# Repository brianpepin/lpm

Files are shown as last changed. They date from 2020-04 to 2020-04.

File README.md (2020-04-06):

# LPM
LPM is a laser power meter used for reading the output power of a laser. It is designed to use a power sensor from Ophir, but any sensor that can produce a linear voltage related to power can be used.  It supplies +12 and -12 volt supplies to the sensor to power it, if needed.

## Features
* 24 bit ADC for precision
* Logging to onboard 64KB flash memory
* Logs viewable graphically and can be output to PC using built-on USB serial port
* Rechargeable battery through USB-C connector
* Software calibration can use any sensor

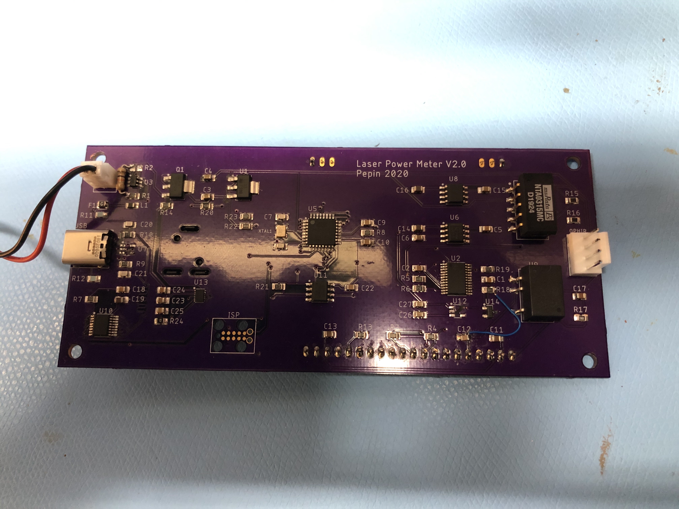
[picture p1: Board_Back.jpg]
Board Back

_(note - the Eagle files included in this repo do not need the jumper and resistor hacks you see here.  They've been fixed)_

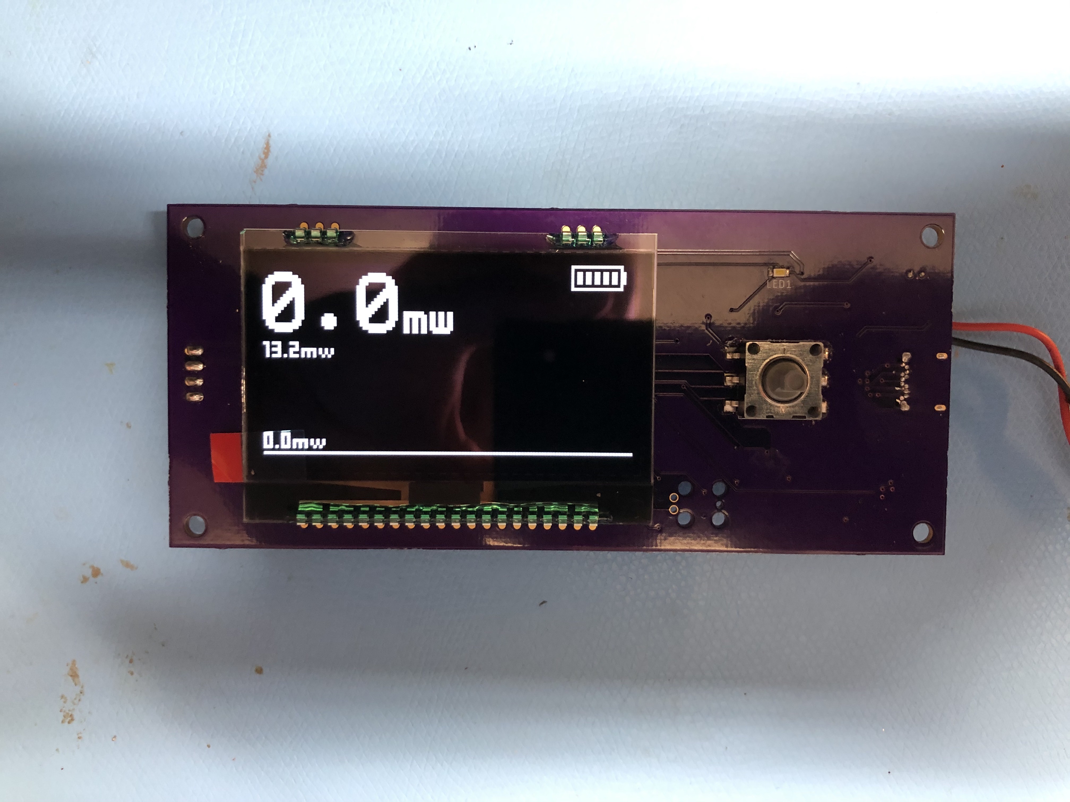
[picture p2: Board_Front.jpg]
Board Front


### Calibration
The board must be calibrated before use.  This can be done through the menu.  Connect a stable voltage source to the sensor input (11.5 volts maximum) and enter the calibration menu.  This will display six digits (###.###), and represents the laser power level at that voltage for the sensor you plan to use.  Use the D-Pad to adjust the digits and click down to accept.

### Usage
Clicking down on the D-Pad turns the unit on. There is an automatic sleep of 10 minutes of inactivity.  Sleep is disabled during logging. Pressing right, left, select or on the D-Pad enters the menu. From here you can zero the max and averages, configure logging cadence or view the log if it exists.  There are also two short-cuts:  down zeros the max and averages and up starts / stops logging. Pressing and holding in the D-Pad for two seconds turns the unit off.

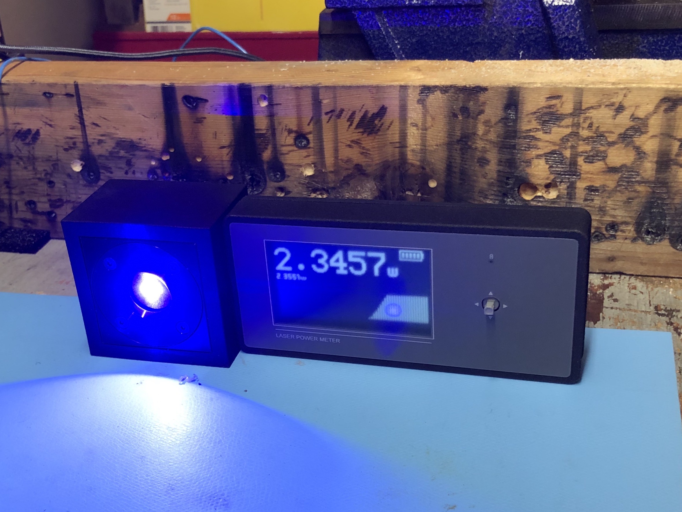
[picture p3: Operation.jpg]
Operation


### Logging
When in logging view you can position the cursor using left and right to show the value at that location.  The log can be sent through USB -- the LPM shows up as a serial port, so you need your own software to pull the log data off.

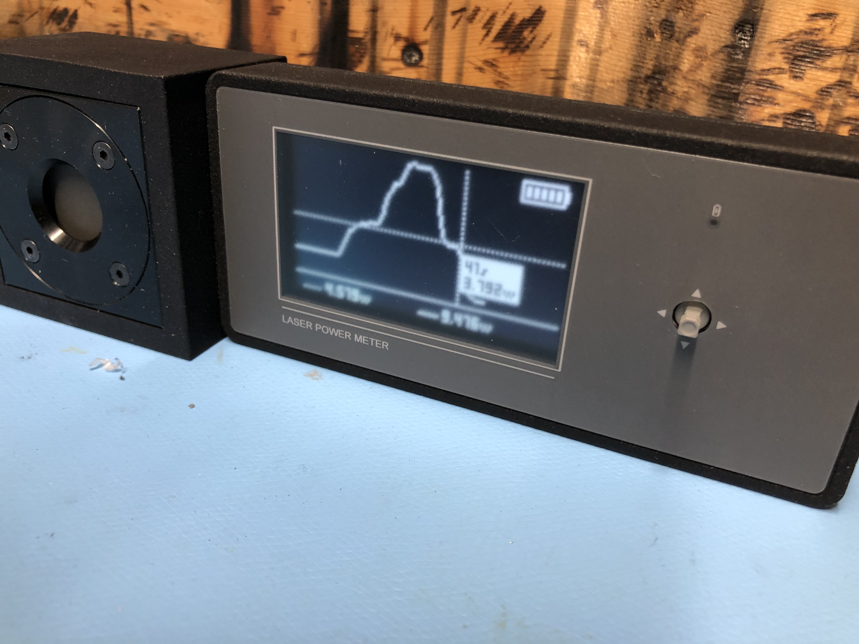
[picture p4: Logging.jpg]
Logging


## Case
I've also included the CAD files (IGES format) of a case that fits this.  I decided to make the sensor and display all part of the same unit so I can just throw it in my toolbox and not have to worry about a bunch of wires.

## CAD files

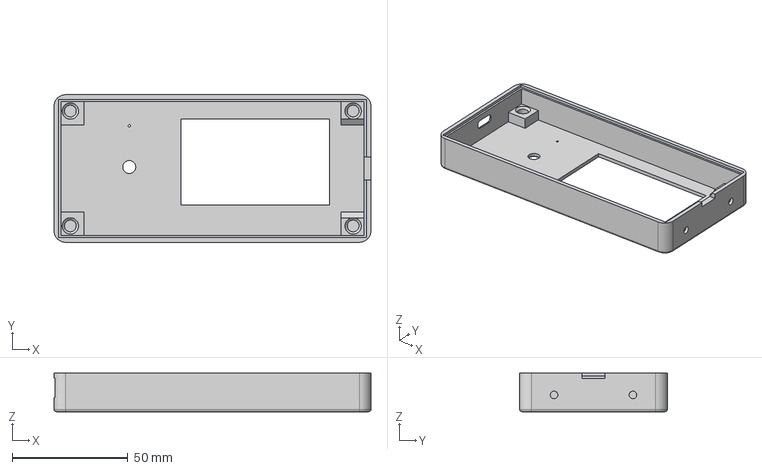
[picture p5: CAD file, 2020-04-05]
case/Top.iges
136.7 x 63.6 x 16.6 mm

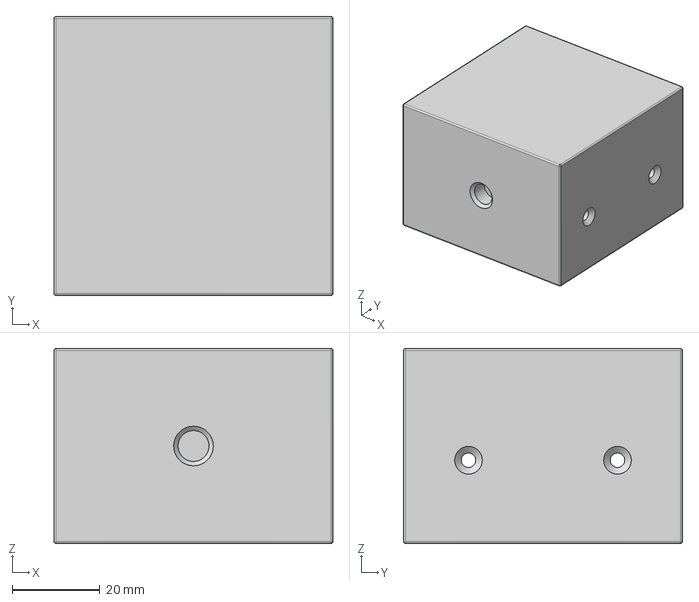
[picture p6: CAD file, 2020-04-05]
case/Sensor Mount.iges
63.7 x 63.6 x 44.5 mm

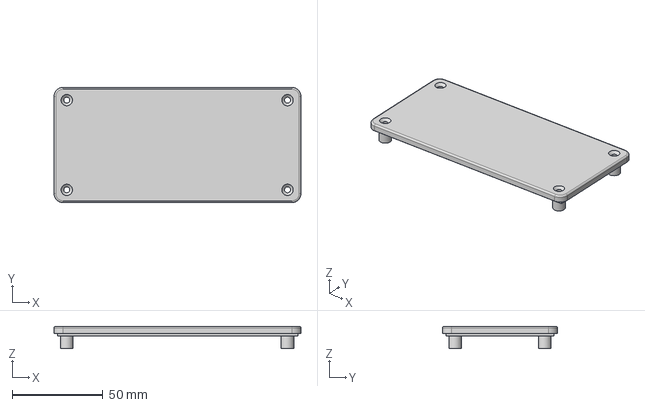
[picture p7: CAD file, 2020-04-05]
case/Bottom.iges
136.4 x 63.6 x 12.3 mm

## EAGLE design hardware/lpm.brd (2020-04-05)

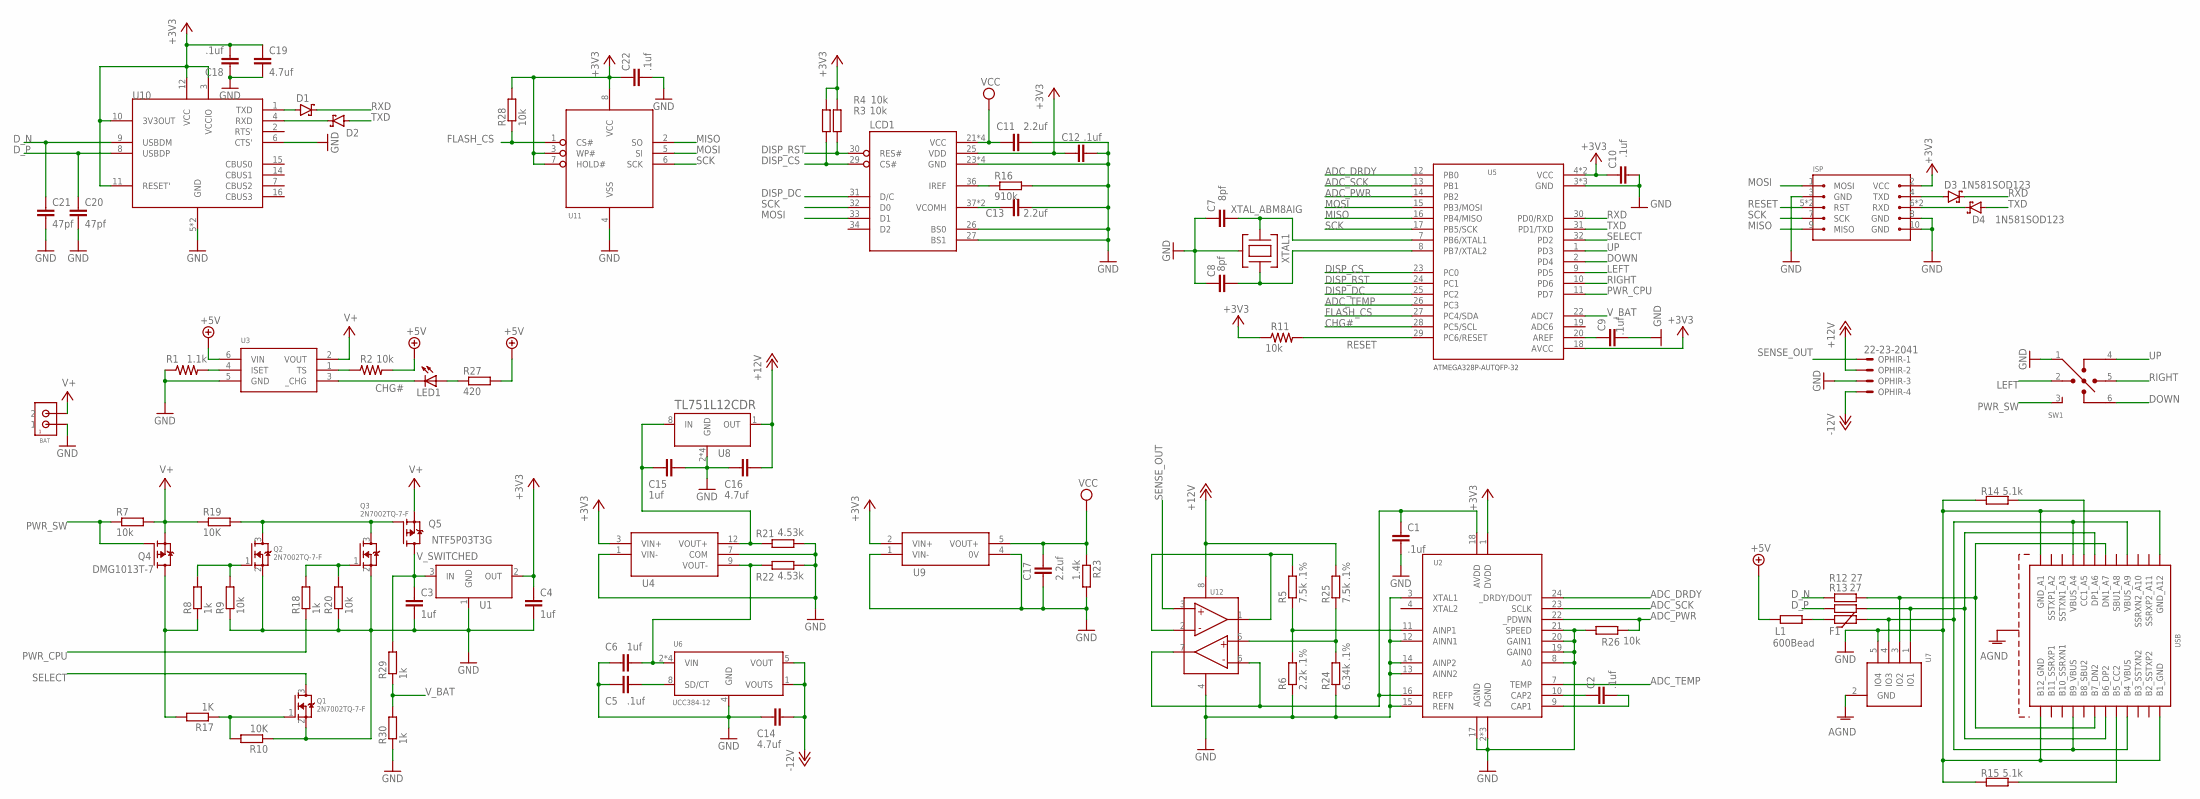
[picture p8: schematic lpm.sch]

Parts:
BAT: 2PIN_CONNJST_SH; JST-SM02B-SRSS-TB
C1, C2, C5, C9, C10, C12, C18, C22: .1uf; C0805
C3, C4, C6, C15: 1uf; C0805
C7, C8: 8pf; C0805
C11, C13, C17: 2.2uf; C0805
C14, C16, C19: 4.7uf; C0805
C20, C21: 47pf; C0805
D1, D2, D3, D4: 1N581SOD123; SOD3715X135
F1: MF-PSHT035KX-2; FUSC2113X120N
ISP: 10PIN_ISPTC2050; TC2050-IDC
L1: 600Bead; M0805
LCD1: EAOLEDL128-6
LED1: LEDCHIPLED_0805; CHIPLED_0805
OPHIR: 22-23-2041
Q1, Q2, Q3: 2N7002TQ-7-F; SOT50P160X80-3
Q4: DMG1013T-7; SOT50P160X80-3
Q5: NTF5P03T3G; SOT230P700X180-4
R1: 1.1k; R0805
R2, R3, R4, R7, R9, R11, R20, R26, R28: 10k; R0805
R5, R25: 7.5k .1%; R0805
R6: 2.2k .1%; R0805
R8, R18, R29, R30: 1k; R0805
R10, R19: 10K; R0805
R12, R13: 27; M0805
R14, R15: 5.1k; M0805
R16: 910k; R0805
R17: 1K; R0805
R21, R22: 4.53k; R0805
R23: 1.4k; R0805
R24: 6.34k .1%; R0805
R27: 420; R0805
SW1: JS-5208
U1: AZ1117E-3.3SOT-223; SOT230P700X180-4
U2: ADS1232; SOP65P640X120-24
U3: BQ21040SOT-23; SOT95P280X145-6
U4: NTA0315MC-R
U5: ATMEGA328P-AUTQFP-32; QFP80P887X887X120-32
U6: UCC384-12; SOIC127P599X175-8
U7: ESDS314; SOT95P282X145-5
U8: TL751L12CDR; SOIC127P599X175-8
U9: ISE0312A
U10: FT230XSSOP16; SOP63P599X175-16
U11: NV25640DWHFT3G; SOIC127P599X175-8
U12: OPA2210VSSOP8; SOP65P490X110-8
USB: USBC_FEMALEUJ31-CH-31-SMT-TR; USBC_UJ31-CH-31-SMT-TR
XTAL1: XTAL_ABM8AIG; XTAL_SMT_3.2X2.5

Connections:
+3V3: C4.1, C10.1, C12.1, C18.2, C19.1, C22.1, ISP.2 (VCC), LCD1.25 (VDD), R3.2, R4.2, R11.1, R28.2, U1.2 (OUT), U2.1 (DVDD), U4.3 (VIN+), U5.4 (VCC), U5.6 (VCC), U5.18 (AVCC), U9.2 (VIN+), U10.3 (VCCIO), U10.10 (3V3OUT), U10.11 (RESET'), U10.12 (VCC), U11.3 (WP#), U11.7 (HOLD#), U11.8 (VCC)
+5V: L1.1, R2.2, R27.2, U3.6 (VIN)
+12V: C16.2, OPHIR.2, R25.2, U8.1 (OUT), U12.8 (V+)
-12V: C14.2, OPHIR.4, U6.1 (VOUTS), U6.5 (VOUT)
ADC_DRDY: U2.24 (_DRDY/DOUT), U5.12 (PB0)
ADC_PWR: R26.2, U2.22 (_PDWN), U5.14 (PB2)
ADC_SCK: U2.23 (SCLK), U5.13 (PB1)
ADC_TEMP: U2.7 (TEMP), U5.26 (PC3)
AGND: U7.2 (GND), USB.SHLD@1 (SHLD), USB.SHLD@2 (SHLD), USB.SHLD@3 (SHLD), USB.SHLD@4 (SHLD), USB.SHLD@5 (SHLD), USB.SHLD@6 (SHLD), USB.SHLD@7 (SHLD), USB.SHLD@8 (SHLD)
CHG#: LED1.C, U3.3 (_CHG), U5.28 (PC5/SCL)
DISP_CS: LCD1.29 (CS#), R4.1, U5.23 (PC0)
DISP_DC: LCD1.31 (D/C), U5.25 (PC2)
DISP_RST: LCD1.30 (RES#), R3.1, U5.24 (PC1)
DOWN: SW1.6 (D), U5.2 (PD4)
D_N: C21.1, R12.1, U10.9 (USBDM)
D_P: C20.1, R13.1, U10.8 (USBDP)
FLASH_CS: R28.1, U5.27 (PC4/SDA), U11.1 (CS#)
GND: BAT.1, C1.2, C3.2, C4.2, C5.1, C6.1, C7.1, C8.1, C9.2, C10.2, C11.2, C12.2, C13.2, C14.1, C15.2, C16.1, C17.2, C18.1, C19.2, C20.2, C21.2, C22.2, ISP.3 (GND), ISP.8 (GND), ISP.10 (GND), LCD1.23 (GND), LCD1.24 (GND), LCD1.26 (BS0), LCD1.27 (BS1), LCD1.28 (GND), LCD1.35 (GND), OPHIR.3, Q1.2 (S), Q2.2 (S), Q3.2 (S), R1.1, R6.1, R9.1, R10.1, R14.1, R15.1, R16.2, R20.1, R21.2, R22.2, R23.2, R24.1, R26.1, R30.1, SW1.1 (C), U1.1 (GND), U2.2 (DGND), U2.3 (XTAL1), U2.5 (DGND), U2.6 (DGND), U2.8 (A0), U2.12 (AINN1), U2.13 (AINN2), U2.14 (AINP2), U2.15 (REFN), U2.17 (AGND), U2.19 (GAIN0), U2.20 (GAIN1), U2.21 (SPEED), U3.5 (GND), U4.1 (VIN-), U4.7 (COM), U5.3 (GND), U5.5 (GND), U5.21 (GND), U6.4 (GND), U7.5 (IO4), U8.2 (GND), U8.3 (GND), U8.6 (GND), U8.7 (GND), U9.1 (VIN-), U9.4 (0V), U10.5 (GND), U10.6 (CTS'), U10.13 (GND), U11.4 (VSS), U12.4 (V-), USB.A1 (GND_A1), USB.A12 (GND_A12), USB.B1 (B1_GND), USB.B12 (B12_GND), XTAL1.2 (CASE), XTAL1.4 (CASE)
LEFT: SW1.2 (L), U5.9 (PD5)
MISO: ISP.9 (MISO), U5.16 (PB4/MISO), U11.2 (SO)
MOSI: ISP.1 (MOSI), LCD1.33 (D1), U5.15 (PB3/MOSI), U11.5 (SI)
unnamed: R1.2, U3.4 (ISET)
unnamed: Q4.3 (D), R8.1, R17.2
unnamed: R2.1, U3.1 (TS)
unnamed: LED1.A, R27.1
unnamed: Q2.1 (G), R8.2, R9.2
unnamed: Q2.3 (D), Q3.3 (D), Q5.1 (G), R19.2
unnamed: R5.1, R6.2, U2.11 (AINP1)
unnamed: C7.2, U5.7 (PB6/XTAL1), XTAL1.1
unnamed: Q3.1 (G), R18.2, R20.2
unnamed: C8.2, U5.8 (PB7/XTAL2), XTAL1.3
unnamed: C9.1, U5.20 (AREF)
unnamed: R14.2, USB.A5 (CC1_A5)
unnamed: R15.2, USB.B5 (B5_CC2)
unnamed: F1.1, L1.2
unnamed: Q1.1 (G), R10.2, R17.1
unnamed: LCD1.36 (IREF), R16.1
unnamed: C13.1, LCD1.37 (VCOMH), LCD1.38 (VCOMH)
unnamed: R24.2, R25.1, U12.5 (IN2+)
unnamed: D3.A, ISP.4 (TXD)
unnamed: D4.C, ISP.6 (RXD), ISP.L6 (RXD)
unnamed: D1.A, U10.1 (TXD)
unnamed: C5.2, U6.8 (SD/CT)
unnamed: C6.2, R22.1, U4.9 (VOUT-), U6.2 (VIN), U6.3 (VIN), U6.6 (VIN), U6.7 (VIN)
unnamed: C15.1, R21.1, U4.12 (VOUT+), U8.8 (IN)
unnamed: D2.C, U10.4 (RXD)
unnamed: R5.2, U12.1 (OUT1), U12.2 (IN1-)
unnamed: C1.1, U2.16 (REFP), U2.18 (AVDD), U12.6 (IN2-), U12.7 (OUT2)
unnamed: R12.2, U7.3 (IO2), USB.A7 (DN1_A7), USB.B7 (B7_DN2)
unnamed: R13.2, U7.1 (IO1), USB.A6 (DP1_A6), USB.B6 (B6_DP2)
unnamed: F1.2, U7.4 (IO3), USB.A4 (VBUS_A4), USB.A9 (VBUS_A9), USB.B4 (B4_VBUS), USB.B9 (B9_VBUS)
unnamed: C2.1, U2.10 (CAP2)
unnamed: C2.2, U2.9 (CAP1)
PWR_CPU: R18.1, U5.11 (PD7)
PWR_SW: Q4.1 (G), R7.1, SW1.3
RESET: ISP.5 (RST), ISP.L5 (RST), R11.2, U5.29 (PC6/RESET)
RIGHT: SW1.5 (R), U5.10 (PD6)
RXD: D1.C, D3.C, U5.30 (PD0/RXD)
SCK: ISP.7 (SCK), LCD1.32 (D0), U5.17 (PB5/SCK), U11.6 (SCK)
SELECT: Q1.3 (D), U5.32 (PD2)
SENSE_OUT: OPHIR.1, U12.3 (IN1+)
TXD: D2.A, D4.A, U5.31 (PD1/TXD)
UP: SW1.4 (U), U5.1 (PD3)
V+: BAT.2, Q4.2 (S), Q5.3 (S), R7.2, R19.1, U3.2 (VOUT)
VCC: C11.1, C17.1, LCD1.21 (VCC), LCD1.22 (VCC), LCD1.39 (VCC), LCD1.40 (VCC), R23.1, U9.5 (VOUT+)
V_BAT: R29.1, R30.2, U5.22 (ADC7)
V_SWITCHED: C3.1, Q5.2 (D), Q5.4 (D), R29.2, U1.3 (IN)

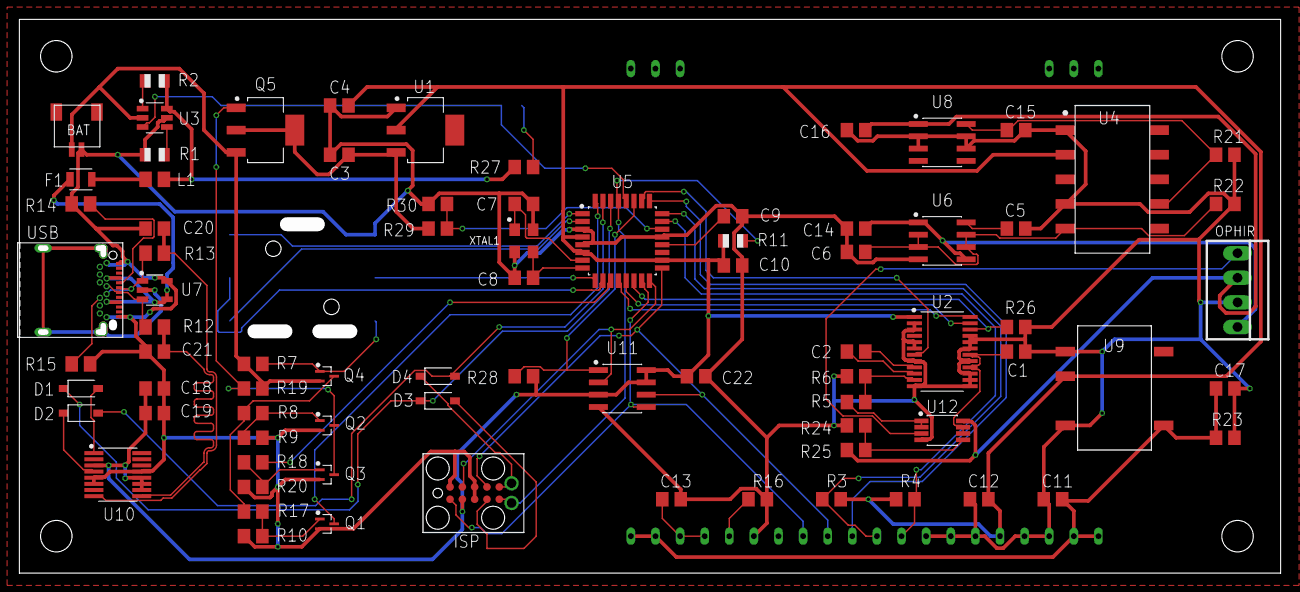
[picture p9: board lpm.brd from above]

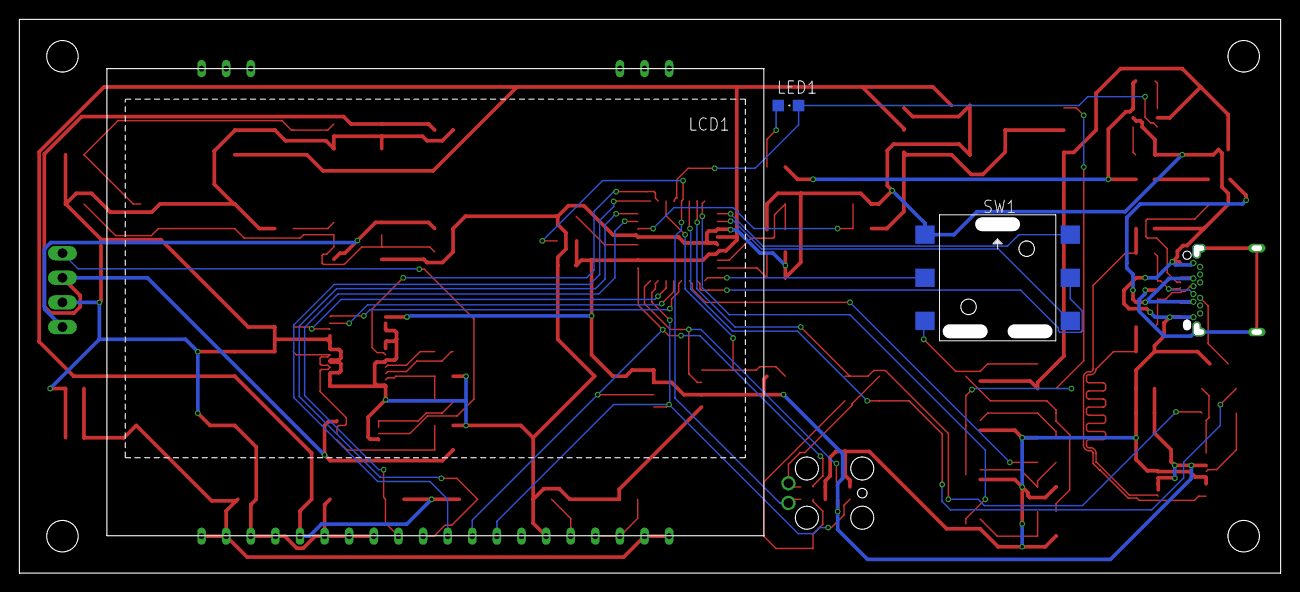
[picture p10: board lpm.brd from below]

Board: 2 copper layers, 130.2 x 57.1 mm, 83 parts (3 on the bottom side), 67 nets.

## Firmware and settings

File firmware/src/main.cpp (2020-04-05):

#include <globals.h>
#include <adc.h>
#include <battery.h>
#include <button.h>
#include <power.h>
#include <flash.h>
#include <logger.h>
#include <views/default.h>

Button buttons[] =
    {
        {PIN_UP, BUTTON_ACTIVE_LOW},
        {PIN_DOWN, BUTTON_ACTIVE_LOW},
        {PIN_LEFT, BUTTON_ACTIVE_LOW},
        {PIN_RIGHT, BUTTON_ACTIVE_LOW},
        {PIN_SELECT, BUTTON_ACTIVE_LOW}
    };

DPad dpad(buttons);
DefaultView defaultView;
View *currentView;

void setup()
{
  Serial.begin(9600);
  
  Power::init();

  display.begin();
  
  Flash::init();
  Adc::init();
  Battery::init();
  Logger::init();

  pinMode(PIN_UP, INPUT_PULLUP);
  pinMode(PIN_DOWN, INPUT_PULLUP);
  pinMode(PIN_LEFT, INPUT_PULLUP);
  pinMode(PIN_RIGHT, INPUT_PULLUP);
  pinMode(PIN_SELECT, INPUT_PULLUP);

  // Start reading all button state
  // so buttons held down during
  // power up are ignored.

  for (unsigned int i = 0; i < COUNT_OF(buttons); i++)
  {
    buttons[i].zero();
  }

  defaultView.init(nullptr);
  currentView = &defaultView;
}

void loop()
{
  DPad::Action action = dpad.read();

  if (action.button == Button_Select)
  {
    Power::processPowerButton(action.state);
  }

  Power::tick();

  if (action.state.changed || Battery::isCharging() || Logger::isLogging())
  {
    Power::resetSleep();
  }

  bool newReading = Adc::update();
  bool updated = currentView->processDpad(action, &currentView);

  updated |= currentView->update(newReading);
  updated |= Battery::update();
  
  if (newReading && Logger::isLogging())
  {
    int32_t reading;
    Adc::read(&reading);

    if (reading < 0)
    {
      reading = 0;
    }

    updated |= Logger::update(reading);
  }

  if (updated)
  {
    display.firstPage();
    display.setFontDirection(0);

    do
    {
      currentView->render();
      Battery::render();
      Logger::render();
    } while (display.nextPage());
  }

  if (Battery::isDepleted())
  {
    Power::turnOff();
  }
}

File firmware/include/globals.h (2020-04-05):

#pragma once

#include <Arduino.h>
#include <SPI.h>
#include <avr/pgmspace.h>

//
// Display port map
//

// DISP_CS:    PC0 pin A0
// DISP_RST:   PC1 pin A1 
// DISP_DC:    PC2 pin A2

#define PIN_DISPLAY_CS    A0
#define PIN_DISPLAY_RST   A1
#define PIN_DISPLAY_DC    A2

//
// AD port map
//

// ADC_DRDY     PB0 pin 8
// ADC_SCK      PB1 pin 9
// ADC_PWR      PB2 pin 10
// ADC_TEMP     PC3 pin A3

#define PIN_ADC_DRDY 8
#define PIN_ADC_SCK  9
#define PIN_ADC_PWR  10
#define PIN_ADC_TEMP A3

//
// D-Pad port map
//

// PWR_CPU      PD7 pin 7
// RIGHT        PD6 pin 6
// LEFT         PD5 pin 5
// DOWN         PD4 pin 4
// UP           PD3 pin 3
// SELECT       PD2 pin 2

#define PIN_PWR_CPU 7
#define PIN_RIGHT   6
#define PIN_LEFT    5
#define PIN_DOWN    4
#define PIN_UP      3
#define PIN_SELECT  2

//
// Battery status port map
//

// CHG      PC5     A5
// V_BAT    ADC7    A7

#define PIN_CHG     A5
#define PIN_V_BAT   A7

//
// Flash Memory port map
//

// FLASH_CS PC4 A4

#define PIN_FLASH_CS A4

// Macros

 #define COUNT_OF(a) (sizeof(a) / sizeof(*a))

// FONTS
#define MENU_HEADER_FONT        u8g2_font_profont11_tr
#define MENU_ITEM_FONT          u8g2_font_profont11_tr
#define MENU_ARROW_FONT         u8g2_font_open_iconic_arrow_1x_t
#define NUMBER_SELECTOR_FONT    u8g2_font_profont17_tn
#define NOTICE_FONT             u8g2_font_haxrcorp4089_tr
#define MAIN_READING_FONT       u8g2_font_profont29_tn
#define MAIN_READING_FONT_SM    u8g2_font_profont22_tn
#define MAIN_UNITS_FONT         u8g2_font_tenthinnerguys_tr
#define GRAPH_READING_FONT      u8g2_font_blipfest_07_tr
#define LOGGING_INDICATOR_FONT  u8g2_font_blipfest_07_tr
